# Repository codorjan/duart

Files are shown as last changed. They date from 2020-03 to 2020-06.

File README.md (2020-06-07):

# DUART Dual Serial Board Designed For RC2014

This is an XR88C681-based serial interface card designed for the RC2014 microcomputer system. This provides two serial interfaces to an RC2014 system in addition to a 16-bit counter/timer and several general-purpose input and output lines.

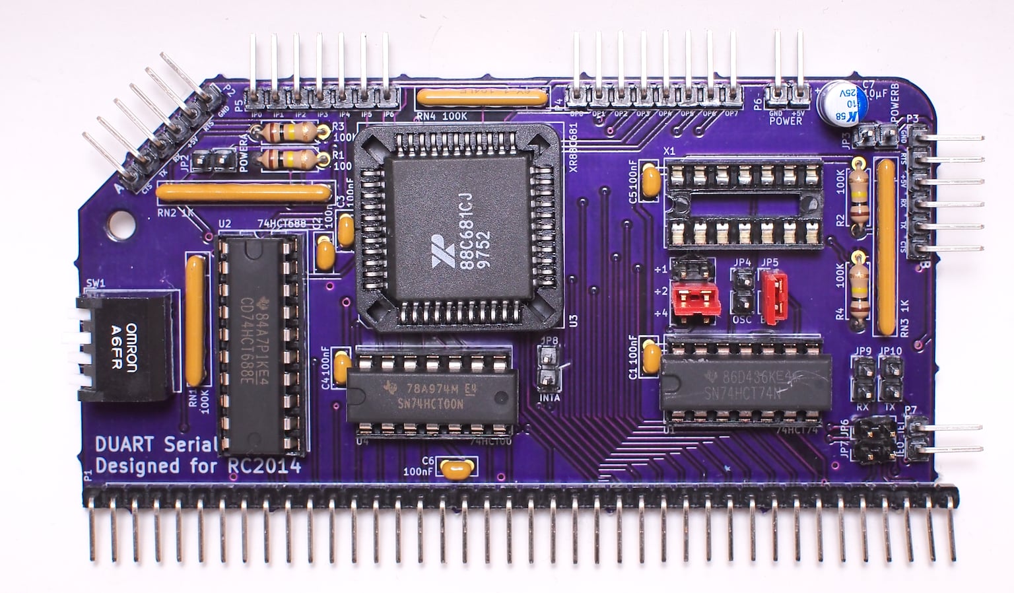
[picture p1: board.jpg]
populated board


The board has undergone limited testing with the [SCM](https://smallcomputercentral.wordpress.com/small-computer-monitor/small-computer-monitor-v1-0/) driver written by Colin MacArthur for Tadeusz Pycio's [XR88C681 board](https://groups.google.com/forum/#!topic/retro-comp/5gGqL3yGzyA) (and it should be fully software compatible with it).

A driver has been incorporated into the dev branch of [RomWBW](https://github.com/wwarthen/RomWBW). This is not currently built into the standard RC2014 ROM but is available in the RCZ80_duart configuration.

## Build Notes

Until this is properly documented, refer to the [schematic](duart.pdf).

The values and types of most components are not critical. Capacitors C1-C6 (100nF, MLCC) are power bypass/decoupling capacitors for each IC and C7 (10µF, electrolytic) provides additional transient decoupling for the DUART itself. RN1 and RN4 (100kΩ) are bussed resistor networks intended to act as pull-ups for the chip select logic (RN1) and to prevent the general purpose inputs (and IM2-specific interrupt lines) from floating (RN4). RN2 and RN3 (1kΩ) are isolated resistor networks intended to provide short-circuit protection to the serial I/O lines. R1 and R2 (100kΩ) pull the serial receive input lines up to their idle state. R3 and R4 (100kΩ) pull the serial /CTS input lines down to their active state.

Oscillator X1 and capacitor C5 are optional in a standard RC2014 system with a 7.3728MHz clock. In this case JP5 should be closed and pins 3 and 4 (CLKDIV2) of JP1 should be bridged with jumpers to provided the DUART with its expected 3.6864MHz clock.

## License

Copyright 2019-2020 Chris Odorjan

This work is licensed under a [Creative Commons Attribution-ShareAlike 4.0 International License](http://creativecommons.org/licenses/by-sa/4.0/).

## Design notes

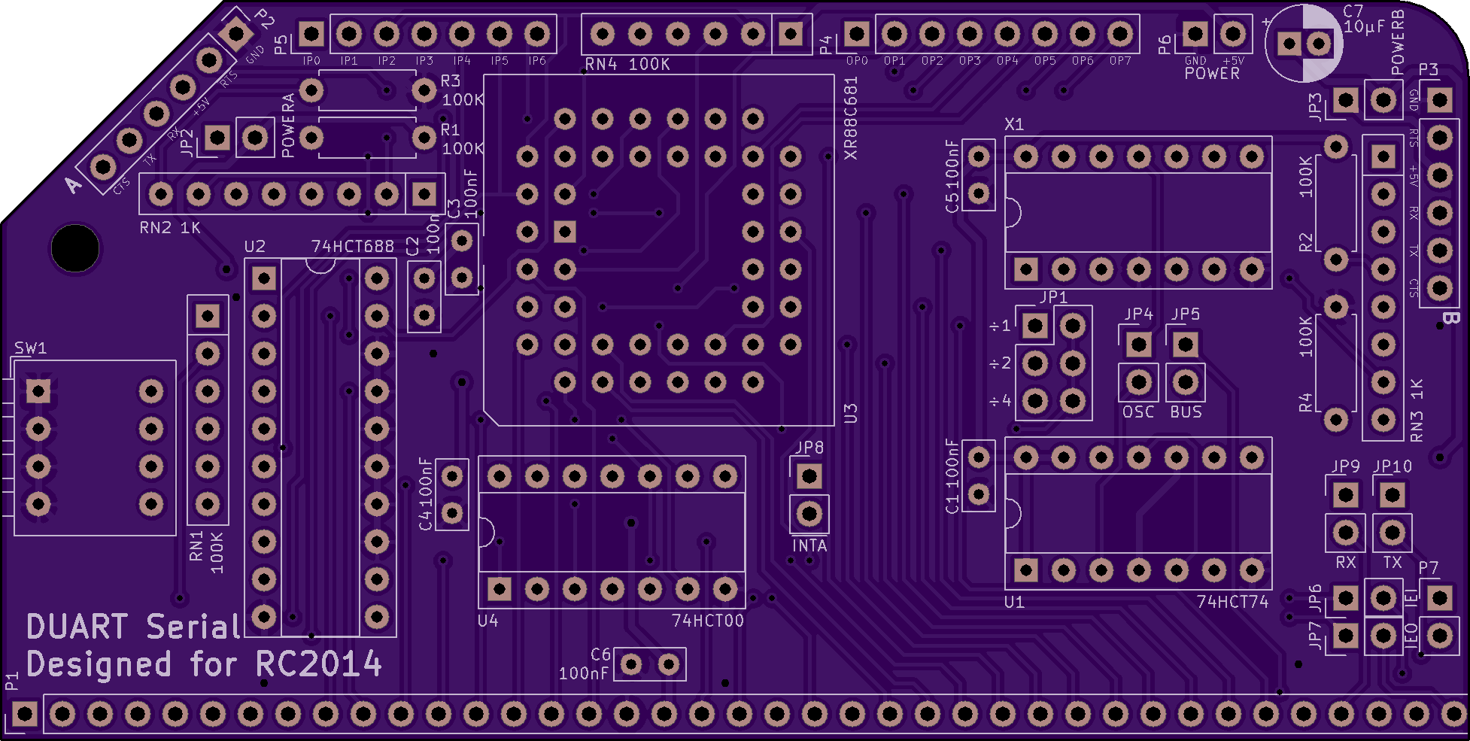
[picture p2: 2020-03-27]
duart-front.png

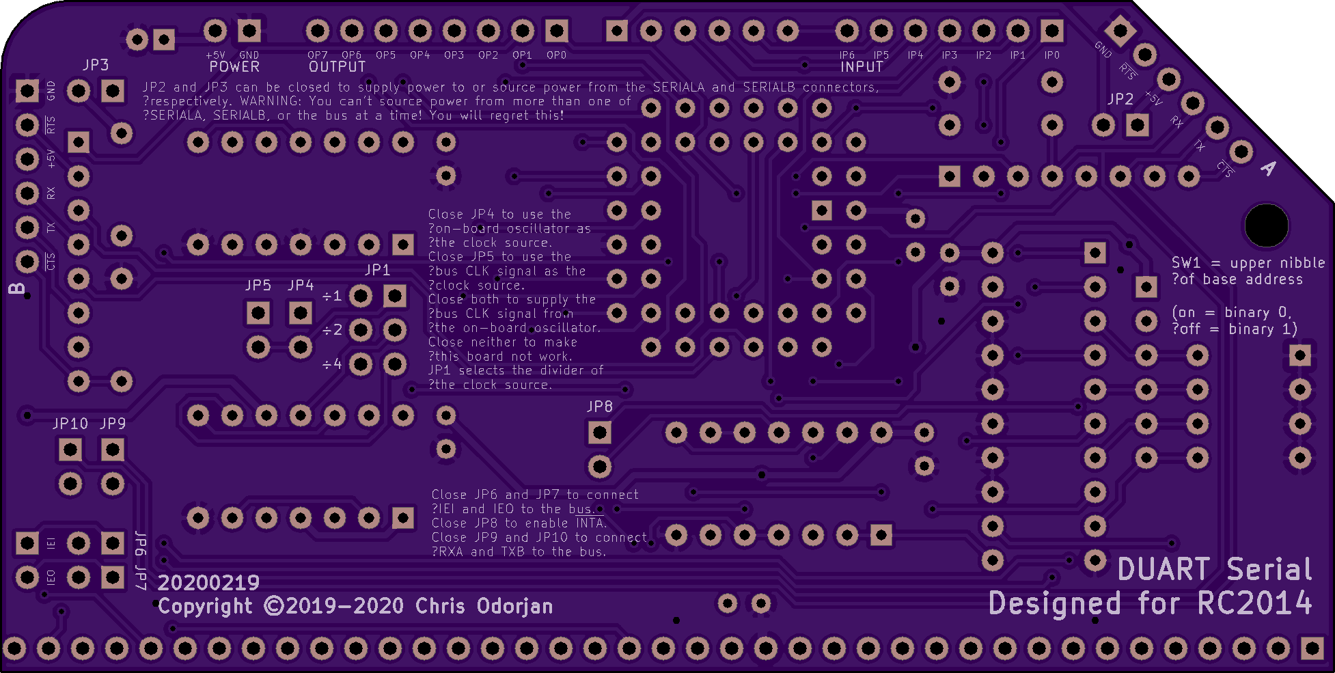
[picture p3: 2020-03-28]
duart-back.png

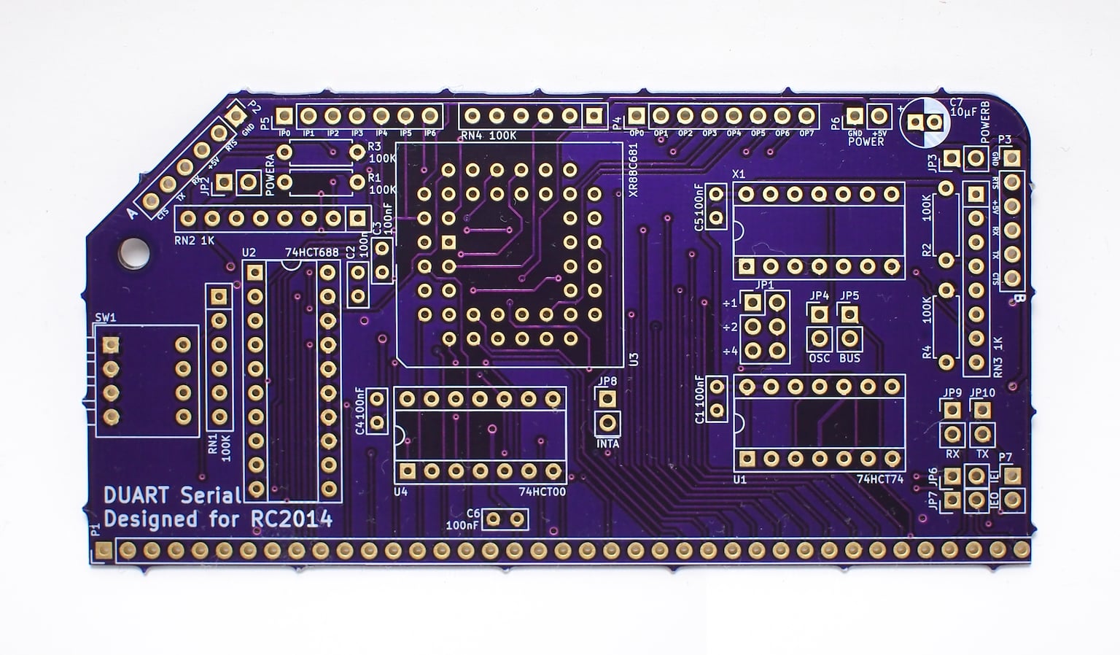
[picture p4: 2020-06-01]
board_empty.jpg

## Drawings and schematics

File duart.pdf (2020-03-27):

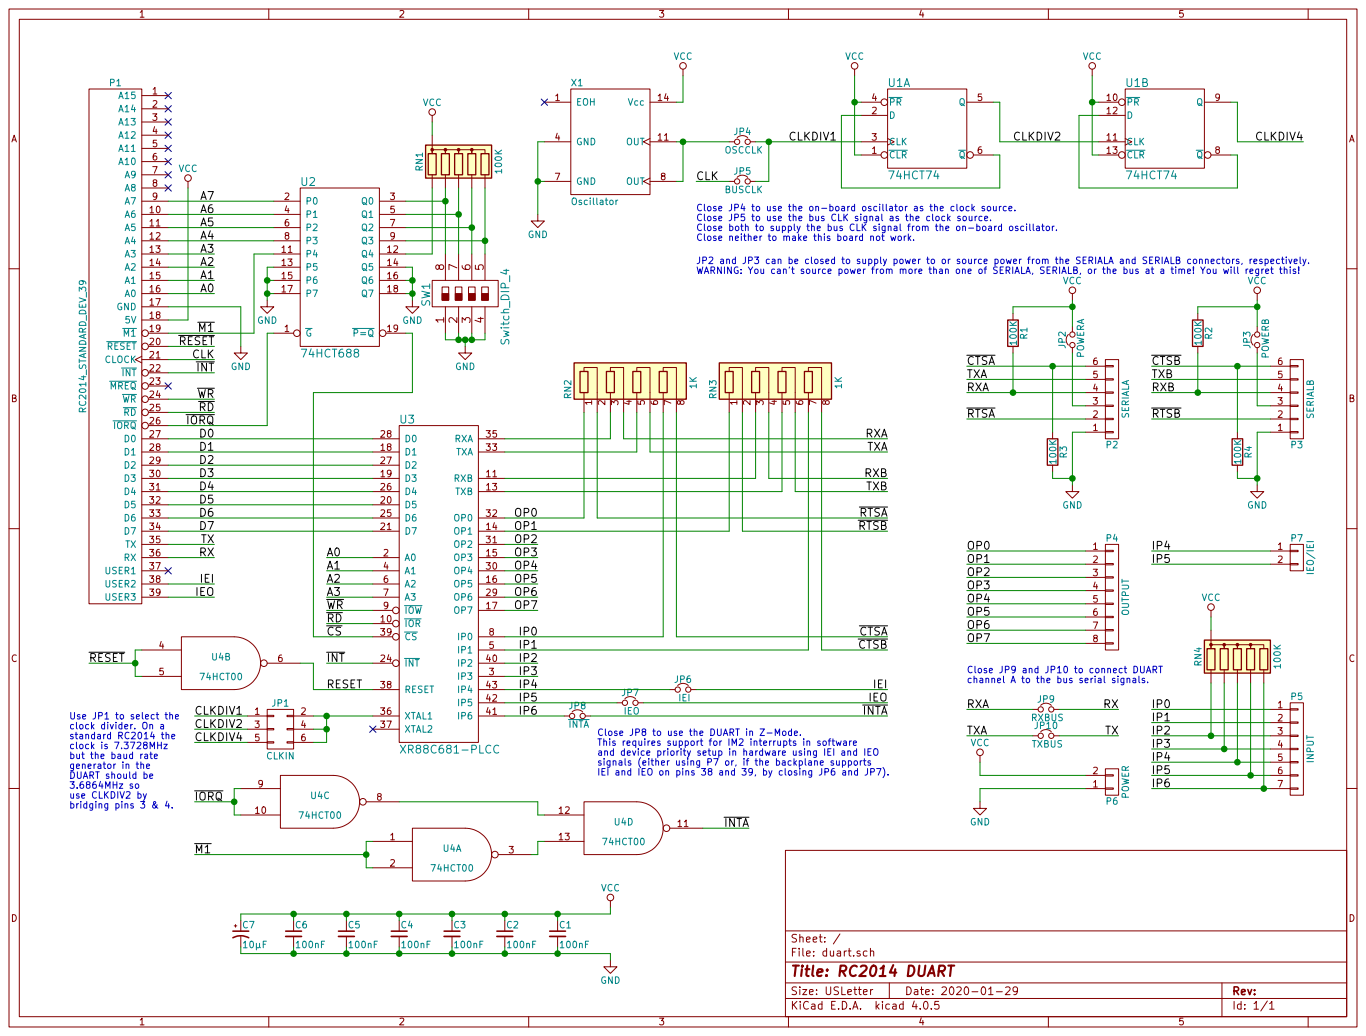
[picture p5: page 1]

Close JP4 to use the on-board oscillator as the clock source. Close JP5 to use the bus CLK signal as the clock source.
Close both to supply the bus CLK signal from the on-board oscillator. Close neither to make this board not work. JP2 and JP3 can be closed to supply power to or source power from the SERIALA and SERIALB connectors, respectively.

WARNING: You can't source power from more than one of SERIALA, SERIALB, or the bus at a time! You will regret this! Close JP8 to use the DUART in Z-Mode. This requires support for IM2 interrupts in software

D0 D1 D2 D3 D4 D5 D6 D7 TXRX

TXB OP0

File: duart.sch Sheet: / A0 2

channel A to the bus serial signals. Use JP1 to select the

3 | JP1 CLKIN CLKDIV1 | 4

INTA
and device priority setup in hardware using IEI and IEO
signals (either using P7 or, if the backplane supports

IP1 | 2
IP2 | 3
IP3 | 4
IP4 | 5
IP5 | 6

clock divider. On a
standard RC2014 the
clock is 7.3728MHz but the baud rate
generator in the DUART should be
3.6864MHz so
use CLKDIV2 by
bridging pins 3 & 4.

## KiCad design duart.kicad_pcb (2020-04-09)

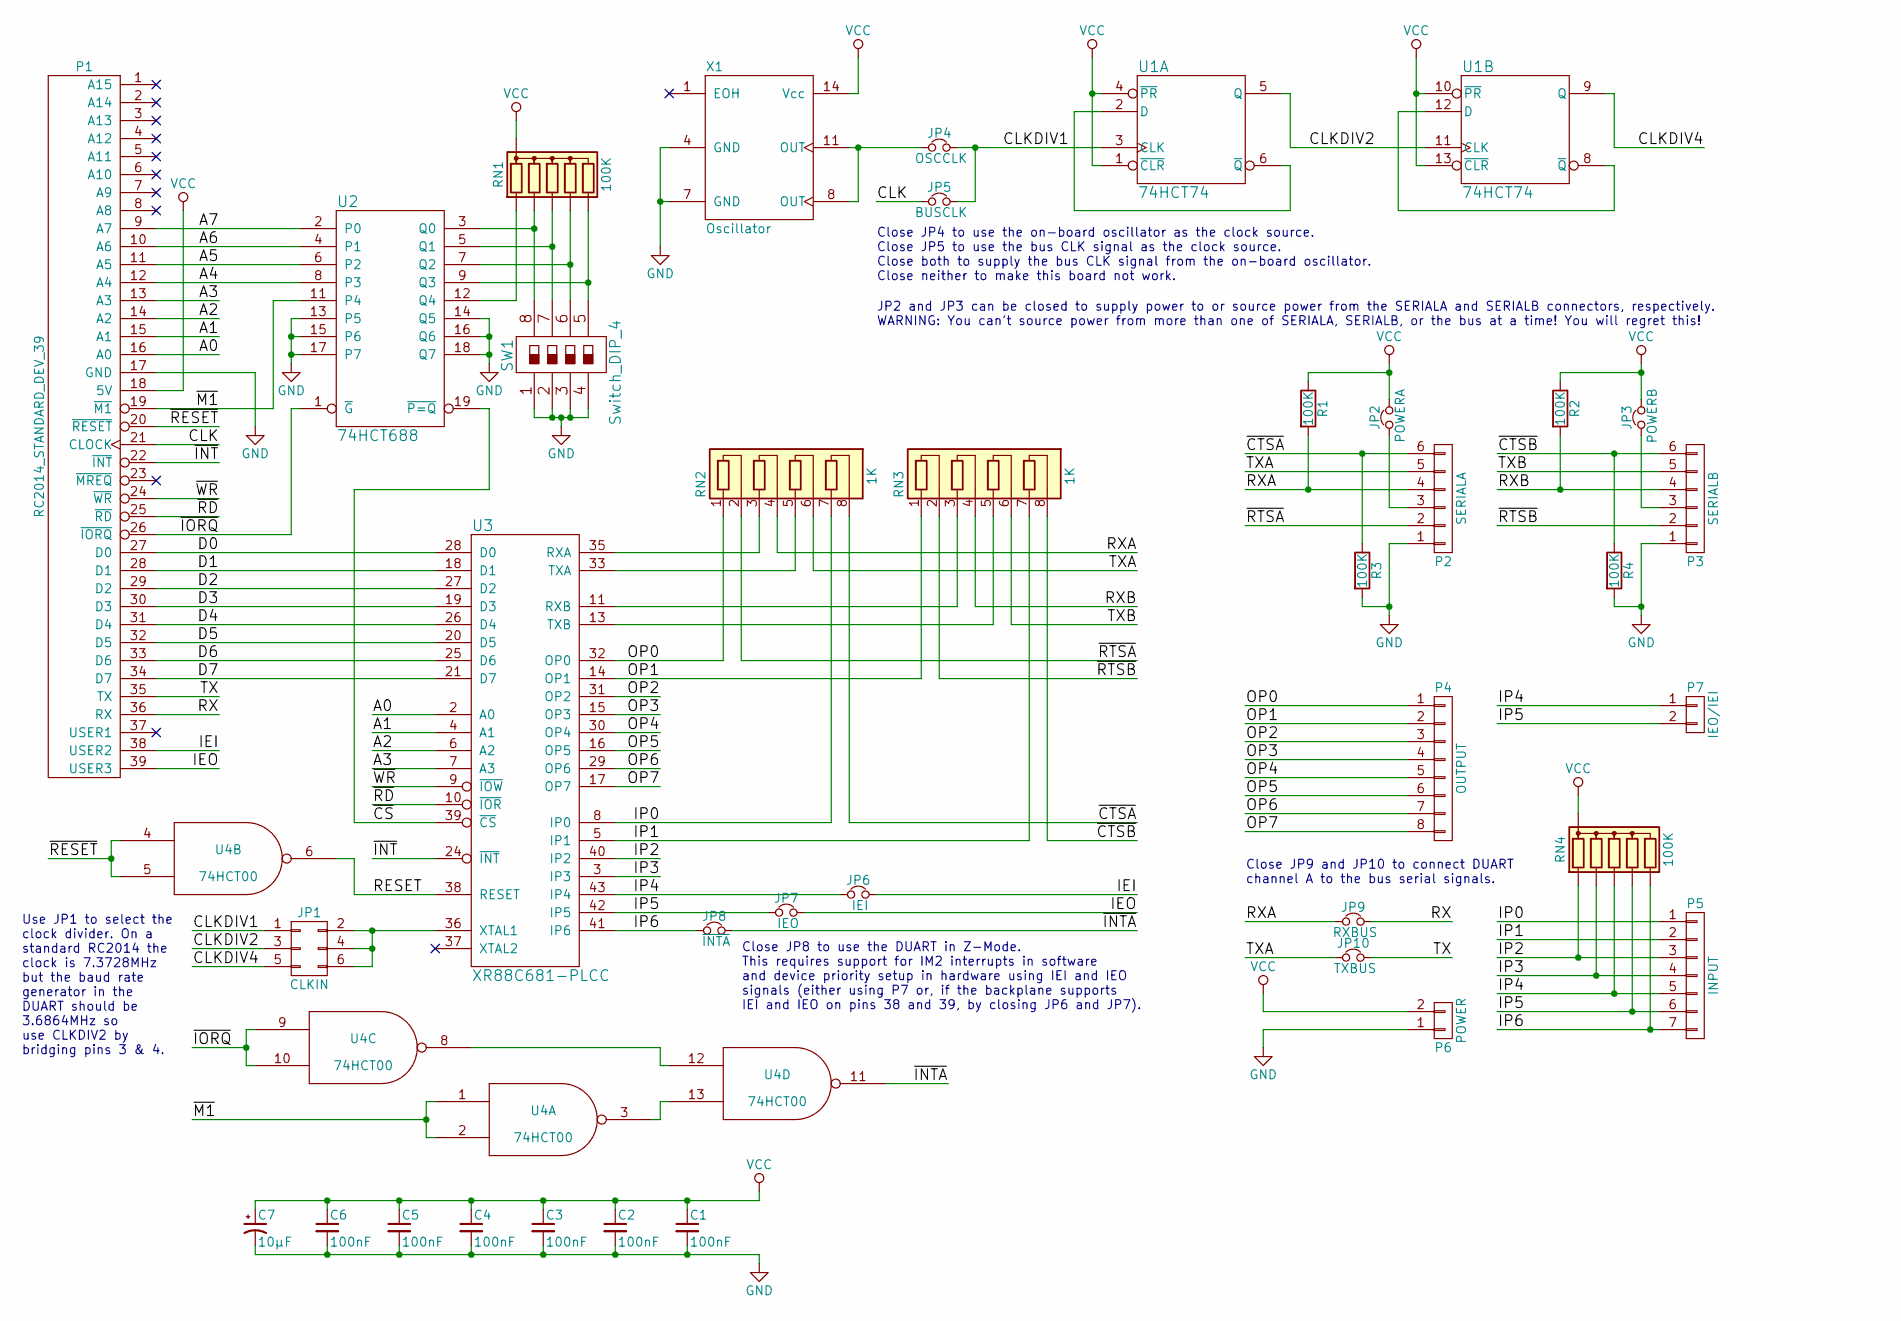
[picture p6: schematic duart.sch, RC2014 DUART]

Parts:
C1, C2, C3, C4, C5, C6: 100nF; C_Rect_L4.6mm_W2.0mm_P2.50mm_MKS02_FKP02
C7: 10µF; CP_Radial_D5.0mm_P2.00mm
JP1: CLKIN; PinHeader_2x03_P2.54mm_Vertical
JP2: POWERA; PinHeader_1x02_P2.54mm_Vertical
JP3: POWERB; PinHeader_1x02_P2.54mm_Vertical
JP4: OSCCLK; PinHeader_1x02_P2.54mm_Vertical
JP5: BUSCLK; PinHeader_1x02_P2.54mm_Vertical
JP6: IEI; PinHeader_1x02_P2.54mm_Vertical
JP7: IEO; PinHeader_1x02_P2.54mm_Vertical
JP8: ~INTA; PinHeader_1x02_P2.54mm_Vertical
JP9: RXBUS; PinHeader_1x02_P2.54mm_Vertical
JP10: TXBUS; PinHeader_1x02_P2.54mm_Vertical
P1: RC2014_STANDARD_DEV_39; PinHeader_1x39_P2.54mm_Vertical
P2: SERIALA; PinHeader_1x06_P2.54mm_Vertical
P3: SERIALB; PinHeader_1x06_P2.54mm_Vertical
P4: OUTPUT; PinHeader_1x08_P2.54mm_Vertical
P5: INPUT; PinHeader_1x07_P2.54mm_Vertical
P6: POWER; PinHeader_1x02_P2.54mm_Vertical
P7: IEO/IEI; PinHeader_1x02_P2.54mm_Vertical
R1, R2, R3, R4: 100K; R_Axial_DIN0207_L6.3mm_D2.5mm_P7.62mm_Horizontal
RN1, RN4: 100K; R_Array_SIP6
RN2, RN3: 1K; R_Array_SIP8
SW1: Switch_DIP_4; SW_DIP_SPSTx04_Piano_10.8x11.72mm_W7.62mm_P2.54mm
U1: 74HCT74; DIP-14_W7.62mm_Socket
U2: 74HCT688; DIP-20_W7.62mm_Socket
U3: XR88C681-PLCC; PLCC-44_THT-Socket
U4: 74HCT00; DIP-14_W7.62mm_Socket
X1: Oscillator; DIP-14_W7.62mm_Socket

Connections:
/A0: P1.16 (A0), U3.2 (A0)
/A1: P1.15 (A1), U3.4 (A1)
/A2: P1.14 (A2), U3.6 (A2)
/A3: P1.13 (A3), U3.7 (A3)
/A4: P1.12 (A4), U2.8 (P3)
/A5: P1.11 (A5), U2.6 (P2)
/A6: P1.10 (A6), U2.4 (P1)
/A7: P1.9 (A7), U2.2 (P0)
/CLK: JP5.1, P1.21 (CLOCK)
/CLKDIV1: JP1.1, JP4.2, JP5.2, U1.3 (CLK)
/CLKDIV2: JP1.3, U1.5 (Q), U1.11 (CLK)
/CLKDIV4: JP1.5, U1.9 (Q)
/D0: P1.27 (D0), U3.28 (D0)
/D1: P1.28 (D1), U3.18 (D1)
/D2: P1.29 (D2), U3.27 (D2)
/D3: P1.30 (D3), U3.19 (D3)
/D4: P1.31 (D4), U3.26 (D4)
/D5: P1.32 (D5), U3.20 (D5)
/D6: P1.33 (D6), U3.25 (D6)
/D7: P1.34 (D7), U3.21 (D7)
/IEI: JP6.2, P1.38 (USER2)
/IEO: JP7.2, P1.39 (USER3)
/IP0: P5.1, RN2.7 (R4.1), U3.8 (IP0)
/IP1: P5.2, RN3.7 (R4.1), U3.5 (IP1)
/IP2: P5.3, RN4.2 (R1), U3.40 (IP2)
/IP3: P5.4, RN4.3 (R2), U3.3 (IP3)
/IP4: JP6.1, P5.5, P7.1, RN4.4 (R3), U3.43 (IP4)
/IP5: JP7.1, P5.6, P7.2, RN4.5 (R4), U3.42 (IP5)
/IP6: JP8.1, P5.7, RN4.6 (R5), U3.41 (IP6)
/OP0: P4.1, RN2.1 (R1.1), U3.32 (OP0)
/OP1: P4.2, RN3.1 (R1.1), U3.14 (OP1)
/OP2: P4.3, U3.31 (OP2)
/OP3: P4.4, U3.15 (OP3)
/OP4: P4.5, U3.30 (OP4)
/OP5: P4.6, U3.16 (OP5)
/OP6: P4.7, U3.29 (OP6)
/OP7: P4.8, U3.17 (OP7)
/RESET: U3.38 (RESET), U4.6
/RX: JP9.2, P1.36 (RX)
/RXA: JP9.1, P2.4, R1.2, RN2.4 (R2.2)
/RXB: P3.4, R2.2, RN3.4 (R2.2)
/TX: JP10.2, P1.35 (TX)
/TXA: JP10.1, P2.5, RN2.6 (R3.2)
/TXB: P3.5, RN3.6 (R3.2)
/~CS: U2.19 (~P=Q), U3.39 (~CS)
/~CTSA: P2.6, R3.1, RN2.8 (R4.2)
/~CTSB: P3.6, R4.1, RN3.8 (R4.2)
/~INT: P1.22 (~INT), U3.24 (~INT)
/~INTA: JP8.2, U4.11
/~IORQ: P1.26 (~IORQ), U2.1 (~G), U4.9, U4.10
/~M1: P1.19 (~M1), U2.11 (P4), U4.1, U4.2
/~RD: P1.25 (~RD), U3.10 (~IOR)
/~RESET: P1.20 (~RESET), U4.4, U4.5
/~RTSA: P2.2, RN2.2 (R1.2)
/~RTSB: P3.2, RN3.2 (R1.2)
/~WR: P1.24 (~WR), U3.9 (~IOW)
GND: C1.2, C2.2, C3.2, C4.2, C5.2, C6.2, C7.2, P1.17 (GND), P2.1, P3.1, P6.1, R3.2, R4.2, SW1.1, SW1.2, SW1.3, SW1.4, U1.7 (GND), U2.10 (GND), U2.13 (P5), U2.14 (Q5), U2.15 (P6), U2.16 (Q6), U2.17 (P7), U2.18 (Q7), U3.22 (GND), U4.7 (GND), X1.4 (GND), X1.7 (GND)
unnamed: JP1.2, JP1.4, JP1.6, U3.36 (XTAL1)
unnamed: JP2.1, P2.3
unnamed: JP3.1, P3.3
unnamed: JP4.1, X1.8 (OUT), X1.11 (OUT)
unnamed: RN1.2 (R1), U2.12 (Q4)
unnamed: RN1.3 (R2), SW1.8, U2.3 (Q0)
unnamed: RN1.4 (R3), SW1.7, U2.5 (Q1)
unnamed: RN1.5 (R4), SW1.6, U2.7 (Q2)
unnamed: RN1.6 (R5), SW1.5, U2.9 (Q3)
unnamed: RN2.3 (R2.1), U3.35 (RXA)
unnamed: RN2.5 (R3.1), U3.33 (TXA)
unnamed: RN3.3 (R2.1), U3.11 (RXB)
unnamed: RN3.5 (R3.1), U3.13 (TXB)
unnamed: U1.2 (D), U1.6 (~Q)
unnamed: U1.8 (~Q), U1.12 (D)
unnamed: U4.8, U4.12
unnamed: U4.3, U4.13
VCC: C1.1, C2.1, C3.1, C4.1, C5.1, C6.1, C7.1, JP2.2, JP3.2, P1.18 (5V), P6.2, R1.1, R2.1, RN1.1 (common), RN4.1 (common), U1.1 (~CLR), U1.4 (~PR), U1.10 (~PR), U1.13 (~CLR), U1.14 (VCC), U2.20 (VCC), U3.44 (VCC), U4.14 (VCC), X1.14 (Vcc)

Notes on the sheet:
Close JP4 to use the on-board oscillator as the clock source. Close JP5 to use the bus CLK signal as the clock source. Close both to supply the bus CLK signal from the on-board oscillator. Close neither to make this board not work.
JP2 and JP3 can be closed to supply power to or source power from the SERIALA and SERIALB connectors, respectively. WARNING: You can't source power from more than one of SERIALA, SERIALB, or the bus at a time! You will regret this!
Close JP8 to use the DUART in Z-Mode. This requires support for IM2 interrupts in software and device priority setup in hardware using IEI and IEO signals (either using P7 or, if the backplane supports IEI and IEO on pins 38 and 39, by closing JP6 and JP7).
Close JP9 and JP10 to connect DUART channel A to the bus serial signals.
Use JP1 to select the clock divider. On a standard RC2014 the clock is 7.3728MHz but the baud rate generator in the DUART should be 3.6864MHz so use CLKDIV2 by bridging pins 3 & 4.

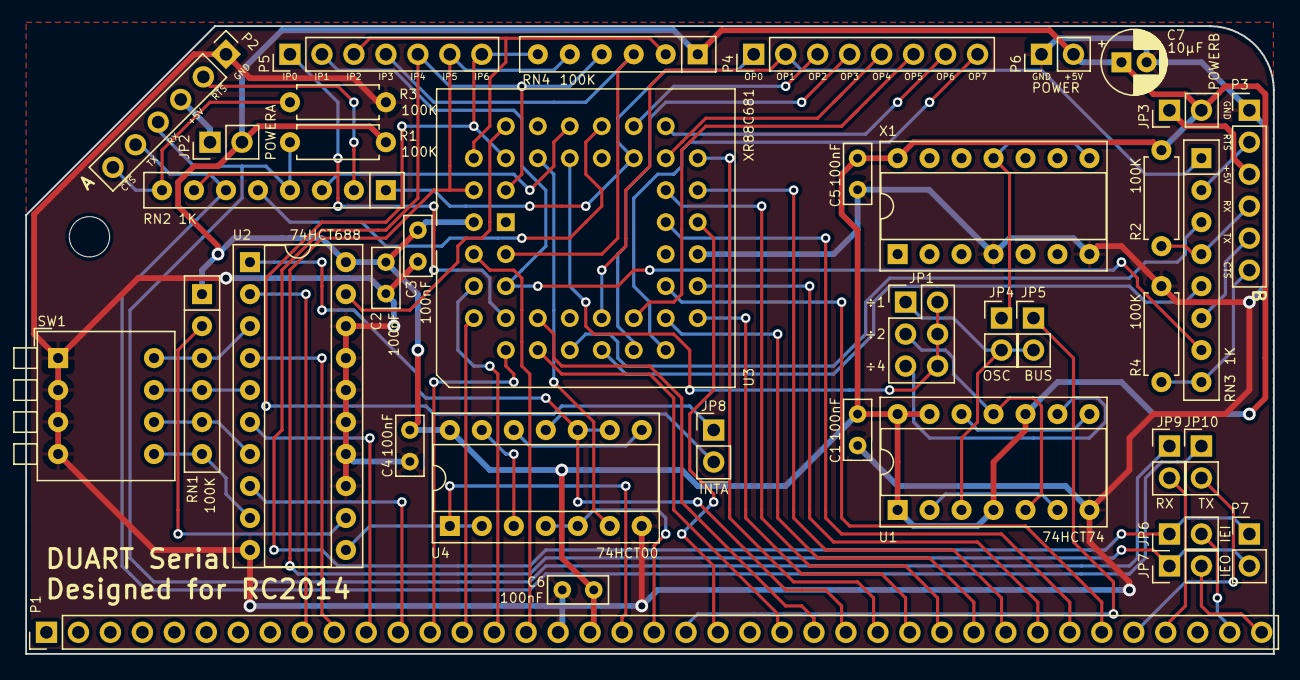
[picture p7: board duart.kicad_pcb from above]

Board: 2 copper layers, 99.1 x 49.9 mm, 38 parts (0 on the bottom side), 75 nets.

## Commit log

2020-04-07 move JP4/JP5 and JP9/JP10 pairs closer together so 2x2 pin headers can be used
    adjust some text
    make references for C2 and C3 easier to read
    don't use tab characters in text, OSH Park renders it as a question mark
    add link to repository
    [duart.kicad_pcb]
2020-04-07 render gerbers
    [duart-B.Cu.gbl, duart-B.Mask.gbs, duart-B.SilkS.gbo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]
2020-04-09 add photos of board
    [duart.kicad_pcb]
2020-06-07 mention RomWBW driver

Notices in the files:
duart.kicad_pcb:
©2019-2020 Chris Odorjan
